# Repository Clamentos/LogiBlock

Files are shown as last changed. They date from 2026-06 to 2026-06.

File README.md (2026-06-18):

# Logi-Block

A simple, small, FPGA inspired, breadboardable logic cell implemented with discrete SMD components. It is composed of a fracturable 4-input LUT and a D-type flip-flop. It can perform any 4-to-1 or 4-to-2 boolean function and it can optionally store the result in its flip-flop. Logi-Block is programmable serially and can be combined with others to implement any logic circuit.

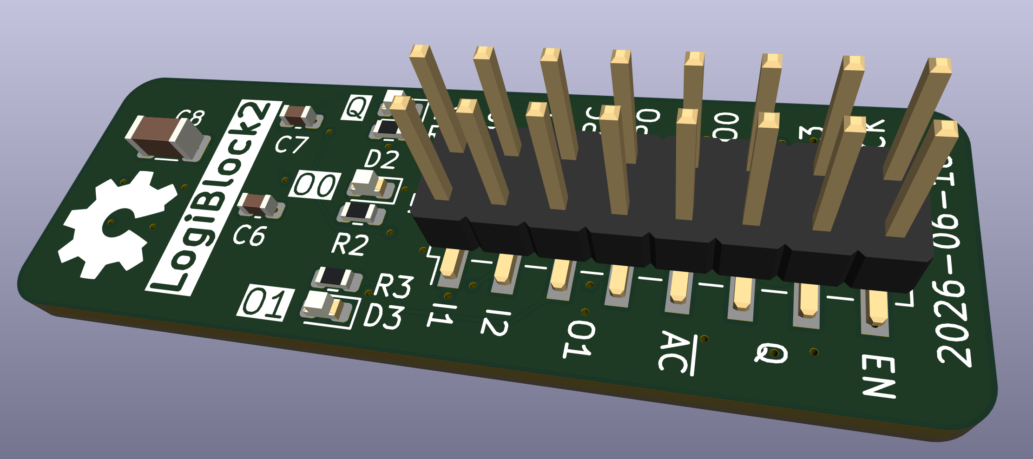
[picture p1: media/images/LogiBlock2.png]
LOGIBLOCK

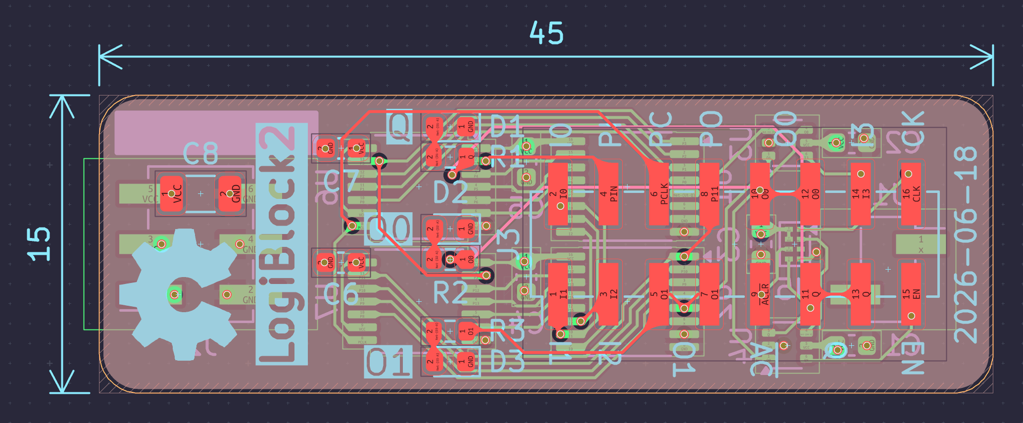
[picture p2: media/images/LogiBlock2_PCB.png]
LOGIBLOCK


*Board revision 2*

### Manufacturing

Production files are provided in the releases section. For JLCPCB, the following files can be used:

- ```Logi-Block_2.zip```: ZIP containing the gerber files.
- ```bom.csv```: The bill of materials CSV file.
- ```positions.csv```: The component placement position CSV file.

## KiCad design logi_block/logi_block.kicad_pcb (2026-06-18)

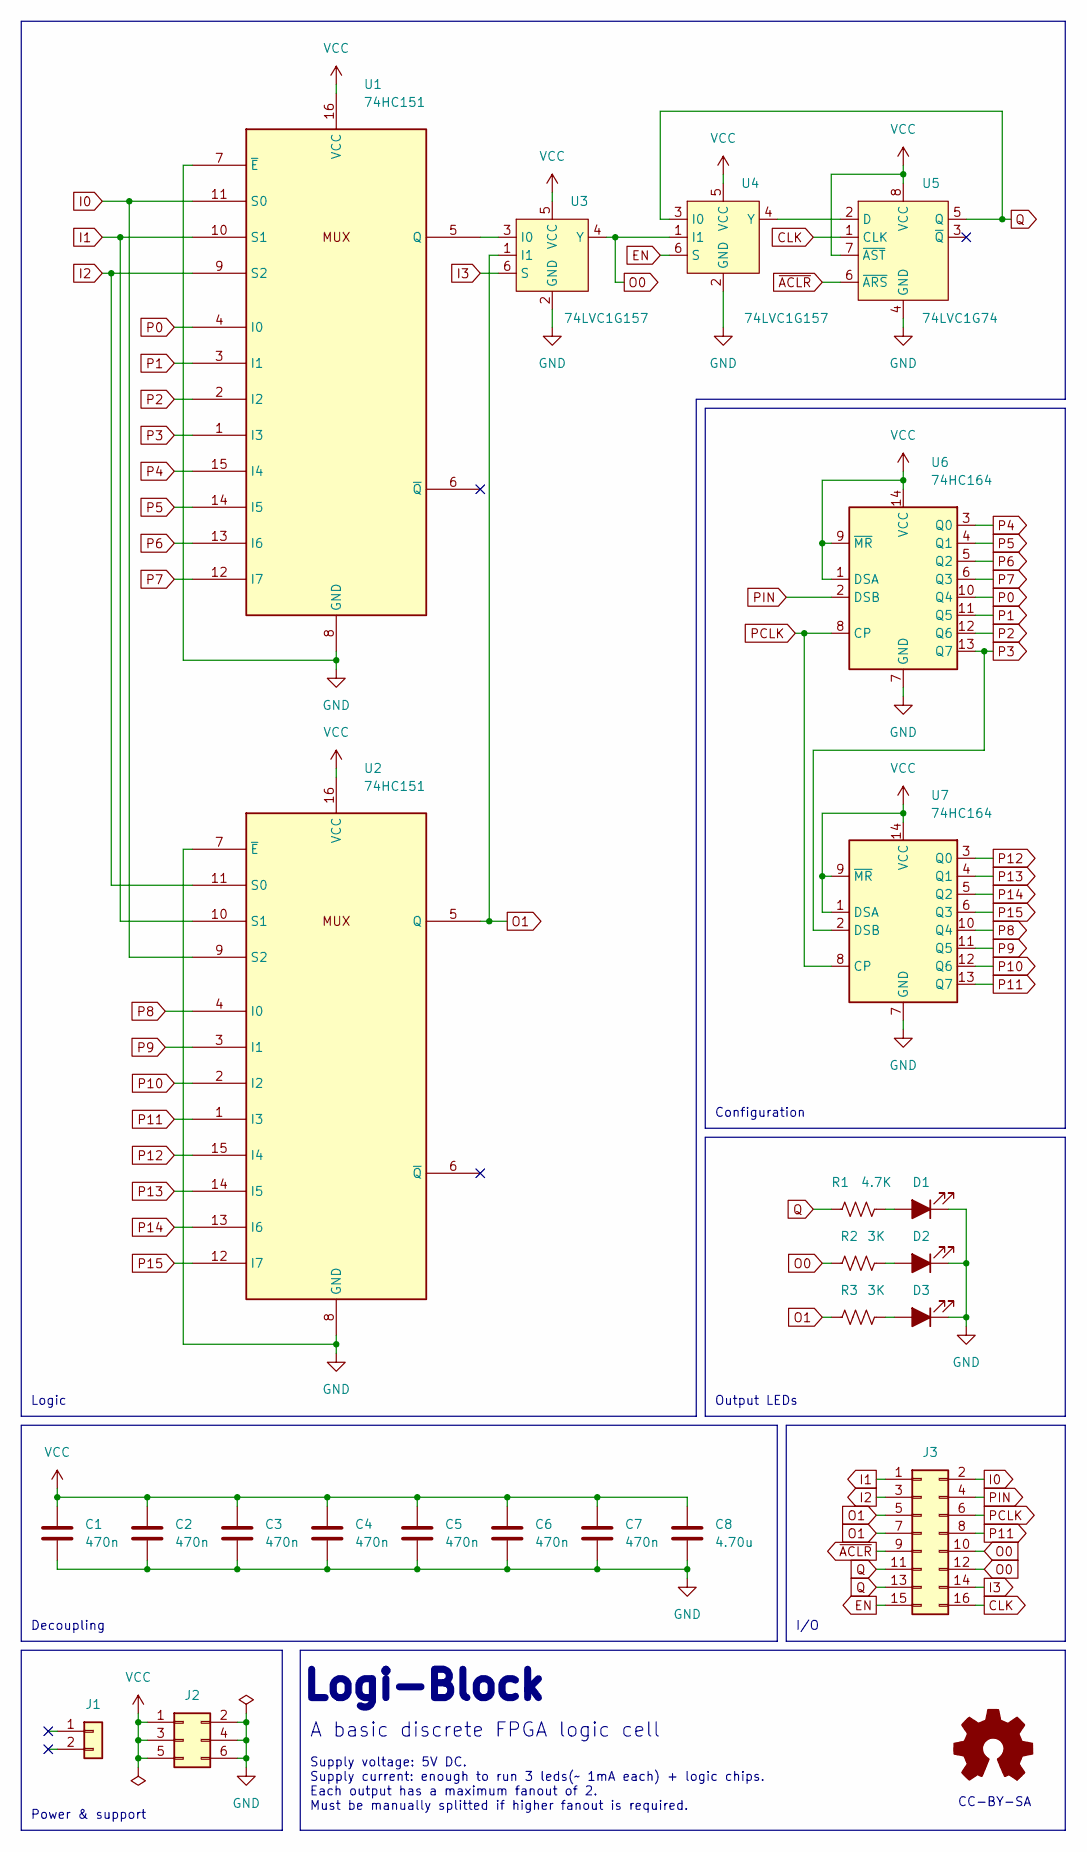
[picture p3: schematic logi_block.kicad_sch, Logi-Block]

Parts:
C1, C2, C3, C4, C5, C6, C7: 470n; C_0603_1608Metric; JLCPCB Part # C1623
C8: 4.70u; C_1206_3216Metric; JLCPCB Part # C29823
D1: LED_Filled; LED_0603_1608Metric; JLCPCB Part # C84267
D2: LED_Filled; LED_0603_1608Metric; JLCPCB Part # C84263
D3: LED_Filled; LED_0603_1608Metric; JLCPCB Part # C84266
J1: Conn_01x02; PinHeader_1x02_P2.54mm_Vertical_SMD_Pin1Left; JLCPCB Part # C5160785
J2: Conn_02x03_Odd_Even; PinHeader_2x03_P2.54mm_Vertical_SMD; JLCPCB Part # C3294461
J3: Conn_02x08_Odd_Even; PinHeader_2x08_P2.54mm_Vertical_SMD; JLCPCB Part # C32713288
R1: 4.7K; R_0603_1608Metric; JLCPCB Part # C23162
R2, R3: 3K; R_0603_1608Metric; JLCPCB Part # C4211
U1, U2: 74HC151; TSSOP-16_4.4x5mm_P0.65mm; JLCPCB Part # C152523
U3, U4: 74LVC1G157; SOT-363_SC-70-6; JLCPCB Part # C135822
U5: 74LVC1G74; XSON-8_L2.0-W1.0-P0.50-BL-A; JLCPCB Part # C548415
U6, U7: 74HC164; TSSOP-14_4.4x5mm_P0.65mm; JLCPCB Part # C406867

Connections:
CLK: J3.16, U5.1 (CLK)
EN: J3.15, U4.6 (S)
GND: C1.2, C2.2, C3.2, C4.2, C5.2, C6.2, C7.2, C8.2, D1.1 (K), D2.1 (K), D3.1 (K), J2.2, J2.4, J2.6, U1.7 (~E), U1.8 (GND), U2.7 (~E), U2.8 (GND), U3.2 (GND), U4.2 (GND), U5.4 (GND), U6.7 (GND), U7.7 (GND)
I0: J3.2, U1.11 (S0), U2.9 (S2)
I1: J3.1, U1.10 (S1), U2.10 (S1)
I2: J3.3, U1.9 (S2), U2.11 (S0)
I3: J3.14, U3.6 (S)
unnamed: D1.2 (A), R1.2
unnamed: D2.2 (A), R2.2
unnamed: D3.2 (A), R3.2
unnamed: U1.5 (Q), U3.3 (I0)
unnamed: U4.4 (Y), U5.2 (D)
O0: J3.10, J3.12, R2.1, U3.4 (Y), U4.1 (I1)
O1: J3.5, J3.7, R3.1, U2.5 (Q), U3.1 (I1)
P0: U1.4 (I0), U6.10 (Q4)
P1: U1.3 (I1), U6.11 (Q5)
P2: U1.2 (I2), U6.12 (Q6)
P3: U1.1 (I3), U6.13 (Q7), U7.2 (DSB)
P4: U1.15 (I4), U6.3 (Q0)
P5: U1.14 (I5), U6.4 (Q1)
P6: U1.13 (I6), U6.5 (Q2)
P7: U1.12 (I7), U6.6 (Q3)
P8: U2.4 (I0), U7.10 (Q4)
P9: U2.3 (I1), U7.11 (Q5)
P10: U2.2 (I2), U7.12 (Q6)
P11: J3.8, U2.1 (I3), U7.13 (Q7)
P12: U2.15 (I4), U7.3 (Q0)
P13: U2.14 (I5), U7.4 (Q1)
P14: U2.13 (I6), U7.5 (Q2)
P15: U2.12 (I7), U7.6 (Q3)
PCLK: J3.6, U6.8 (CP), U7.8 (CP)
PIN: J3.4, U6.2 (DSB)
Q: J3.11, J3.13, R1.1, U4.3 (I0), U5.5 (Q)
VCC: C1.1, C2.1, C3.1, C4.1, C5.1, C6.1, C7.1, C8.1, J2.1, J2.3, J2.5, U1.16 (VCC), U2.16 (VCC), U3.5 (VCC), U4.5 (VCC), U5.7 (~AST), U5.8 (VCC), U6.1 (DSA), U6.9 (~MR), U6.14 (VCC), U7.1 (DSA), U7.9 (~MR), U7.14 (VCC)
~ACLR: J3.9, U5.6 (~ARS)

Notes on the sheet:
A basic discrete FPGA logic cell
Supply voltage: 5V DC. Supply current: enough to run 3 leds(~ 1mA each) + logic chips. Each output has a maximum fanout of 2. Must be manually splitted if higher fanout is required.
CC-BY-SA
Decoupling
I/O
Power & support
Logic
Configuration
Output LEDs
Logi-Block

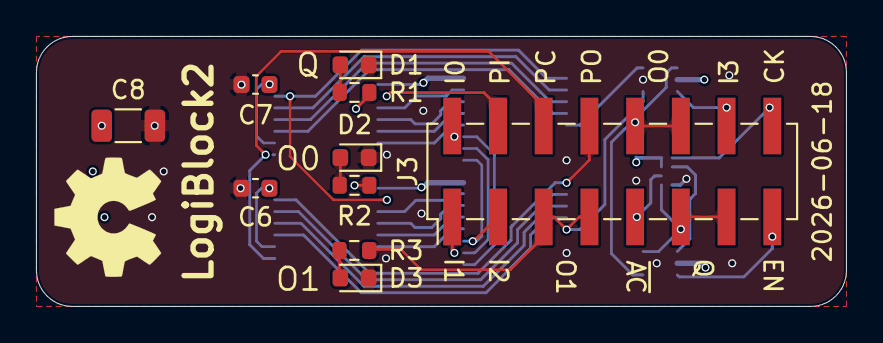
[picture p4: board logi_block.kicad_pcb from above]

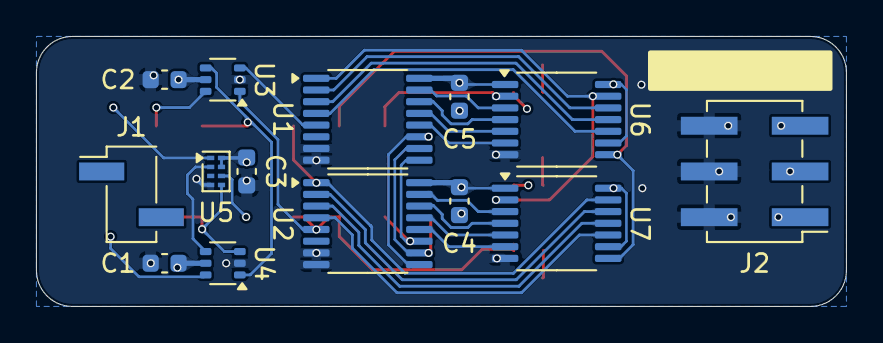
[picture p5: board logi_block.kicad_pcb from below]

Board: 6 copper layers, 45.0 x 15.0 mm, 24 parts (14 on the bottom side), 35 nets.

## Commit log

2025-10-18 Repo init.
    [logi_block.kicad_pcb, logi_block.kicad_sch]
2026-06-18 Maintenance on schematic Maintenance on PCB (changed serial number for JLCPCB) Added local datasheets Remade pictures Other small refactors...
    [logi_block.kicad_pcb, logi_block.kicad_sch]
